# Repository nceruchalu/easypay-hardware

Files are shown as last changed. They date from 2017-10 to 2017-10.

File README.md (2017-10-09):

# EasyPay

Demo Video Click to watch EasyPay demo (https://www.youtube.com/watch?v=BhdTa_jyTG4)

## About EasyPay
| | |
| --- | --- |
| Author  | Nnoduka Eruchalu |
| Date | 05/16/2013 |
| Website | http://nnoduka.com/made/easypay/ |

EasyPay was intended to be Nigeria's One-Stop Payments Solution. It aimed to
support payments for multiple services like cellphone topup, water, power, TV
bills with hopes of expanding into retail and transportation someday.

## Documentation
* [**How it Works**](Documentation/HowItWorks.md): Notes on intended application
* [**Demo**](Documentation/Demo.md): Showcase of product features

## Repository Contents
| Module | Description |
| --- | --- |
| **/Documentation** | Design notes, datasheets, reference notes |
| **/Firmware** | Embedded C project |
| **/Hardware** | Altium design files |
| **/Production** | Production files used for printing PCBs |

## Version History
* 1.0.0: Demo Product

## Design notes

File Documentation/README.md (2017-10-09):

# Documentation

This directory contains documentation on the product modules.

## Directories

Brief description of directories. Add a brief description when adding a new
directory. Keep list in alphabetical order.

### [/Datasheets](Datasheets)
Resource files used in designing the circuit hardware.

## Modules

Brief description of modules. Add a brief description when adding a new module.
Keep list in alphabetical order.

### [Data.md](Data.md)
3G + GPS module for use in communication with the web server.

### [Demo.md](Demo.md)
Description and video of user interface created to showcase product features.

### [Enclosure.md](Enclosure.md)
Product enclosure details

### [Headers.md]([Headers.md)
Header and receptacle descriptions.

### [HowItWorks.md](HowItWorks.md)
Short description on the intended usage of the product

### [Keypad.md](Keypad.md)
Matrix keypad scanning, anti-aliasing, and interrupt generation.

### [LCD.md](LCD.md)
4x20 Character LCD connection and power up/down.

### [MCU.md](MCU.md)
PIC18F MCU configuration and clock choice (and how it relates to UART).

### [MIFARE.md](MIFARE.md)
MIFARE summary notes and testing strategy.

### [PCB.md](PCB.md)
PCB design requirements.

### [Power.md](Power.md)
Generation of 3.3V (for the MCU and peripherals) and 3.8V (for the data module)
regulated voltages from the battery voltage.

### [StateMachine.xlsx](StateMachine.xlsx)
Firmware's state machine design.

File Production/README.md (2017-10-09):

# Production

This directory contains the production files used for printing PCBs.

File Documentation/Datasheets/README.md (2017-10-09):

# Documentation/Datasheets

This directory contains resource files used in designing the circuits and
product.

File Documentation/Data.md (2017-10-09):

# Data Module

## Overview
[SIM5218](http://simcom.ee/modules/wcdma-hspa/sim5218/), a 3G + GPS module.

### Bands
Quad-band GSM/GPRS/EDGE and UMTS that works on frequencies of:
GSM 850MHz, EGSM 900MHz, DCS 1800MHz, PCS 1900MHz and WCDMA 900MHz/2100MHz

These work for:
* US bands:
  - 2G: GSM 850, GSM 1900
  - 3G: UMTS 850, UMTS 1900, UMTS 1700, UMTS 2100

* Nigeria bands:
  - 2G: GSM 900, GSM 1800
  - 3G: UMTS 2100

### Antenna
The antenna connector (module side) is MURATA MM9329-2700

### Connector
70 pins board-to-board

### I/O
Inputs pulled down (unless explicitly instructed otherwise) to minimize noise.

### Sim Card
Keep USIM peripheral circuit close to USIM card socket.

### Power
Required input Voltage Source = 3.4V to 4.2V
Normal value is 3.8V (so we use that!)
        
Current drawn could get up to 2A, so power supply should be able to do that.
        
**Note** that supply power should NEVER drop below 3.4V even in a transmit burst
during which current consumption may rise up to 2A.

### Power On/Off
Will do this via the POWER_ON pin (PIC's DATAPOWER) because it seems you can't
turn on the SIM5218A with AT commands.
To do this I will use an NPN transistor switch (really an inverting buffer)

More on transistor switches here:
* http://www.technologystudent.com/elec1/transis1.htm
* http://hyperphysics.phy-astr.gsu.edu/hbase/electronic/transwitch.html
        
More on inverting buffers here:
* http://hyperphysics.phy-astr.gsu.edu/hbase/electronic/buffer.html#c4

**Note** that the POWER_ON pin has been pulled up in module, so the internal
pull up counts as the load on the Collector.

### Reset
Just like the Power_ON pin, it has been pulled up in module, so will use a
similar switch.

### UART
UART_RX line has VIHmax = VDD_EXT + 0.3 = 2.6V + 0.3 = 2.9V
This means we need to use a  buffer to convert the RX input from the PIC to an
appropriate voltage. This will be done with an SN74LVC1G126. The voltage level
of the buffer will be set by the module's VREG_AUX which is set at 2.85V.

The UART_TX line has VOHmax = VDD_EXT = 2.6V and VOHmin = VDD_EXT-0.2 = 2.4V
So this doesn't have to be buffered because it goes into the PIC and the PIC can
handle Voltages less than VCC (3.3V).
Also the PIC's VIHmin for Schmitt Trigger inputs is 0.8V, so 2.4V isnt a too low
VIN. The PIC's USART pins are Schmitt Trigger inputs.

### Camera
No need to pull low (to prevent floating inputs)
Will be configured as GPIO (AT+CCGSWT)
Inputs pulled low to prevent floating inputs -- waste of power

### GPIO4
Pull high to turn off flight mode (RF is working)

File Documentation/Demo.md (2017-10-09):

# Product Demo
## User Interface
#### Keypad:
```
+---------------------------+
| 1       2       3       A |
|                           |
| 4       5       6       B |
|                           |
| 7       8       9       C |
|                           |
| *       0       #       D |
+---------------------------+
```

#### Display:
###### Welcome Screen:
```
+--------------------+
|-Welcome to EasyPay-|
|                    |
| Tap Card to Start  |
|                    |
+--------------------+
```

###### On Card Tap --> Enter Pin Screen:
```
+--------------------+           +--------------------+ 
|-    Enter Pin     -|           |-    Enter Pin     -|
|        _           |  <0..9>   |        ****        |
|*Exit*           → C|   ==>     |*Undo*           → C|
|*Done*           → D|           |*Done*           → D| 
+--------------------+           +--------------------+
```

###### On Correct Pin --> Home Screen:
Press buttons indicated on right to navigate
```
+--------------------+ 
|EasyAccount      → A|
|Parking          → B|
|Mobile Recharge  → C|
|Utility Bills    → D|
+--------------------+
```

###### EasyAccount Screen:
```
+--------------------+ 
|-   EasyAccount    -|
|Balance: N50,000.00 |
|Recharge         → C|
|*Exit*           → D|
+--------------------+
```

###### Parking Screen:
```
+--------------------+           +--------------------+ 
|- Pay for Parking  -|           |- Pay for Parking  -|
|Enter Space: 010_   |    <D>    |Enter Time: 0:30_   |
|                    |    ==>    |                    |
|*Done*           → D|           |*Done*           → D|
+--------------------+           +--------------------+ 
```

###### Mobile Recharge:
```
+--------------------+           +--------------------+ 
|- Mobile Recharge  -|           |*Back*           → A|
|MTN              → B|    <D>    |Airtel           → B|
|GLO              → C|    ==>    |Etisalat         → C|
|*More*           → D|           |*Exit*           → D|
+--------------------+           +--------------------+ 
```

###### Utility Bills:
```
+--------------------+           +--------------------+   
|-  Utility Bills   -|           |- Utility: Power   -|
|Power            → B|    <B>    |Amount: N10,000.00_ | 
|Water            → C|    ==>    |                    | 
|*Exit*           → D|           |*Done*           → D|
+--------------------+           +--------------------+
```

## Video
Click on the video below to see  a demo of the prototype module in action:

Demo Video (https://www.youtube.com/watch?v=BhdTa_jyTG4)

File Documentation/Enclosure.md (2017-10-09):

# Enclosure
## Overview
[OKW Enclosures A9061119](https://www.okwenclosures.com/en/Hand-Held-Boxes/A9061119.htm)

## Dimensions
Margins defined as dimension from exterior of enclosure to interior (pcb space)

### Top/Bottom margin calculation
    155 + 25 - 168 = 12mm
    So top/bottom margin = 12/2 = 6mm

### Left/Right margin calculation
    100-91 = 9
    So top/bottom margin = 9/2 = 4.5mm

### Inner space
    height                                    = 13.7 + 16.2 - 3      = 26.9mm
    height [sans pillars and other obstacles] = 9.7 + 16.2 - 5 - 2.8 = 18.1mm

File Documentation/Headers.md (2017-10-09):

# Headers and Receptacles
## Headers
    P1 - short (6 pins)            ICSP connector
    P2 - short/long (6 pins)       UART (uses jumper wires)
    P3 - short (8 pins)            Keypad connector
    P4 - external, short (6 pins)  RFID module
    P5 - long (16 pins * 2)        On pcb and lcd modules (use jumpers wires)
                                   * Should have used short
    P6 - short (3 pins)            LCD power selector (use jumpers)
    P8 - short  (8 pins)           Test points for power [**optional**]
 
    P7 - JST (2 pins)              External PWR connector (solder stranded wire)
    S2 - JST (2 pins)              System power switch (solder stranded wire)
    BT1 - JST (2 pins)             Battery connector

## Receptacles
    P4 - short(6 pins)              RFID receptacle

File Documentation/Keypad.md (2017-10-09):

# Keypad

## Module
[27899PAR-ND](https://www.digikey.com/product-detail/en/parallax-inc/27899/27899PAR-ND/3523678)

## 4x4 Matrix Layout

                    |Col0       |Col1       |Col2       |Col3
                    |           |           |           |
                    |           |           |           |
             ___/ --x    ___/ --x    ___/ --x    ___/ --x
    Row0     | SW0  |    | SW1  |    | SW2  |    | SW3  |
    ---------x------|----x------|----x------|----x------|
                    |           |           |           |
                    |           |           |           |
             ___/ --x    ___/ --x    ___/ --x    ___/ --x
    Row1     | SW4  |    | SW5  |    | SW6  |    | SW7  |
    ---------x------|----x------|----x------|----x------|
                    |           |           |           |
                    |           |           |           |
             ___/ --x    ___/ --x    ___/ --x    ___/ --x
    Row2     | SW8  |    | SW9  |    | SW10 |    | SW11 |
    ---------x------|----x------|----x------|----x------|
                    |           |           |           |
                    |           |           |           |
             ___/ --x    ___/ --x    ___/ --x    ___/ --x
    Row3     | SW12 |    | SW13 |    | SW14 |    | SW15 |
    ---------x------|----x------|----x------|----x------|

Keyboards use a matrix with the rows and columns made up of wires. Each key acts
like a switch. When a key is pressed, its column and row wires make contact.

## Scanning to Detect Key Presses
I order to detect key presses, the MCU (Micro Controller Unit) will scan all
rows, activating each one by one. When a row is activated, the MCU detects
columns are activated.

The row values will be active low outputs from the MCU (Micro Controller Unit).
So they are inputs into the keypad.

The column values will be active low inputs into the MCU.
So they are outputs from the keypad.
Since these are active low they have to be puled up by default, to an inactive
state.

Assuming the data for the rows are sent out in nibbles having Row3 as MSB and
Row0 as LSB i.e. (Row3, Row2, Row1, Row0), when we scan we get:

    row 0, send out 1110
    row 1, send out 1101
    row 2, send out 1011
    row 3, send out 0111

If Switch8 happens to be pressed when row 2 is activated (1011), then the MCU
input from the columns nibble (Col3, Col2, Col1, Col0) will be 1110 because
Column 0 will now be active.

### Multiple Keys Pressed
#### In a situation where SW0,1,5 are pressed:
* When scanning Row0, 1110 is sent out and the input to the MCU is 1100 showing
  SW0 and SW1 are pressed.
* When scanning row 1, 1101 is sent out and the input to the MCU is still 1100
  implying SW4 and SW5 are pressed. But SW4 isn't pressed!

#### Here is Why (Intro to Ghosting)
* When Row1 is set to 0, SW5 being pressed pulls down Col1.
* However SW1 is connected to Col1, and SW1 connects Col1 to Row0. So Row0
  is activated to a 0, despite the MCU setting it to 1.
* Remember SW0 connects Row0 to Col0, so SW0 activates Col0 as it did when Row0
  was activated by the MCU.
* So the MCU reads in a keypad value with both Col1 and Col0 activated, hence
  1100. This is called **ghosting**!

#### Masking
We have defined ghosting. Masking is the reverse.
If SW0,1,4,5 were all pressed, and SW0 was released the MCU wouldn't know, as it
would again assume all 4 keys were still pressed. This is called **masking**!

#### Problem for MCU (And Solution)
Let's work with the ghosting case. The real issue was that Row0 was activated
by SW1 even when the MCU was attempting to deactivate it. This creates a
conflict and surely cannot be good for the MCU; it is indirectly setting an I/O
pin both active and inactive at the same time. You want to protect the MCU from
this, and you need diodes for this!

Position diodes on all the output pins of the MCU with the cathode (-ve) at the
MCU and the anode at the keypad.

This won't solve ghosting, but it protects the MCU from receving a 0 on Row0
when it is setting it to a 1. Remember how diodes work: the anode have to be at
a higher potential than the cathode by at least the forward voltage for any
current to flow.

                     |Vcc        |Vcc        |Vcc        |Vcc
                     |           |           |           |
                   |---|       |---|       |---|       |---|  
                   |   |       |   |       |   |       |   |
                   |10K|       |10K|       |10K|       |10K|
                   |   |       |   |       |   |       |   |
                   |---|       |---|       |---|       |---|
              Col0   |    Col1   |    Col2   |    Col3   |                
              -------|    -------|    -------|    -------|
                     |           |           |           |
              ___/ --x    ___/ --x    ___/ --x    ___/ --x
    Row0      | SW0  |    | SW1  |    | SW2  |    | SW3  |
    ----|<|---x------|----x------|----x------|----x------|
                     |           |           |           |
                     |           |           |           |
              ___/ --x    ___/ --x    ___/ --x    ___/ --x
    Row1      | SW4  |    | SW5  |    | SW6  |    | SW7  |
    ----|<|---x------|----x------|----x------|----x------|
                     |           |           |           |
                     |           |           |           |
              ___/ --x    ___/ --x    ___/ --x    ___/ --x
    Row2      | SW8  |    | SW9  |    | SW10 |    | SW11 |
    ----|<|---x------|----x------|----x------|----x------|
                     |           |           |           |
                     |           |           |           |
              ___/ --x    ___/ --x    ___/ --x    ___/ --x
    Row3      | SW12 |    | SW13 |    | SW14 |    | SW15 |
    ----|<|---x------|----x------|----x------|----x------|

Make your life easy and use 1N4148 switching diodes.

#### How to fix Aliasing (Ghosting and Masking)
The 4 diodes placed on the rows will protect the MCU but won't solve aliasing.
To solve ghosting let's look back at our example. We need that Row0 will not be
activated by SW1 while scanning Row1. To do this we need a diode between SW1 and
Row0, with the cathode at Row0.

This has to be built into they keypad. You cannot add this in external circuitry

##### Ref
http://www.dribin.org/dave/keyboard/one_html/

## Keypad Interrupts
To conserve power, the MCU should be able to go to sleep.
Before it does that, all rows should be activated by setting them to 0. This
means that when any key is pressed, the corresponding MCU input will be 0.
Remember that the MCU inputs are the keypad columns which are pulled-up to Vcc,
so a Diode-Resistor AND gate should be placed on the columns. The idea is once
one Column goes from 1 to 0, then the output of the gate will go from 1 to 0,
and create a pulse that should be connected to an MCU SYSTEM_WAKEUP pin.
            
                Vcc
                 |
               +---+
               |   |
               |10K|
               +---+
                 |
    Col0 --|<|---+------- SYSTEM WAKEUP (Col0 & Col1 & Col2 & Col 3)
                 |
    Col1 --|<|---+
                 |
    Col2 --|<|---+
                 |
    Col3 --|<|---+

##### Ref
https://en.wikipedia.org/wiki/Diode_logic#AND_logic_gate

## Connector
    Black           White

    R1 R2 R3 R4     C1 C2 C3 C4

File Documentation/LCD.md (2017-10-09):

# LCD
## Module
[NHD-0420AZ-FSW-GBW-33V3](http://www.newhavendisplay.com/specs/NHD-0420AZ-FSW-GBW-33V3.pdf)

## Backlight
Typical specs: 3.0V and 15mA

However system voltage is 3.3V, so the solution here is to burn off the extra
0.3V across a series resistor. If this resistor has 15mA passing through it,
to burn off 0.3V we need 0.3/0.015 Ohms = 20 Ohms.
Backlight series resistor will be 20 Ohms.

## Power
Supply Power Typical specs: 3.3V, 2mA
Supply Power Max specs:     5.5V, 3mA

This means the system uses a total of (15 + 3)mA between VDD and backlight.
Lets put this at 20mA tops.

The LCD power (VCCLCD) could come from:
* The system, VCC
* The MCU PIC, VCCLCD_PIC.
  The PIC MCU's PortA<7:6>, PortB, PortC can output up to 25mA.

Using VCCLCD_PIC has the advantage of being able to turn off the LCD module
via the PIC.
After some testing, will see if this is a viable solution.

## Contrast
Using a 10KOhms potentiometer to decide on the contrast.
Eventually this should be replaced by either a pull-up or pull-down, for 
maximum contrast.

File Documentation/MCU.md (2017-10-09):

# Micro Controller Unit (MCU)
## Module
[PIC18F67K22](http://www.microchip.com/wwwproducts/en/PIC18F67K22)

## Low Power Tips 'n Tricks
* Using I/O pins to power external components:
  - **LCD**: VCCLCD_PIC is a PIC I/O line powering LCD since LCD utilized less
    than 20mA
  - **RFID Module**: Work current could get up to 45mA, so cant power with a
    PIC I/O, so will send the Power Down commands and use the wakeup signal to
    restart it.
  - **Data Module**: Again draws high current (and uses 3.8V) so cant power via
    I/O, so will send Power Down and Power Up signals to it.

* Will be in sleep mode when not active, and will be woken up by SYSTEM_WAKEUP
  interrupt from the keypad

* Configuring Port Pins:
  Unused Port Pins: will be configured as output pins driving to either state
  (high or low).

* Using high-value pull up resistors (10K Ohms)

## External Clock (SG636PCE 18.4320MC0)
Using a high precision external clock of 18.432MHz to have 0% Baud Rate Error.
The desired Baud rate is 115.2KHz, to satisfy the default value of the data
module.

## On-Chip Regulator
This is enabled

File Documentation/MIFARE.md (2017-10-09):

# MIFARE 
## MIFARE Classic Intro
http://www.ladyada.net/products/rfidnfc/mifare.html

## MIFARE DESFire
Model:                     MF3 1C D40
Free Space:                4K
Max. Apps:                 28
Max. Keys per app.:        14 (counting master key 0) [for apps AID != 0x00 ]
Max. Files per app.:       16
Crypto:                    DES, 3DES
Support for ISO 7816 Cmds: Very Limited

'Compatible Crypto Mode' must be used

MiFare DESFire are iso14443A compliant contactless smartcards, and support all
layers including iso4443-4. Think of these cards as memory cards
with access control. 

The new DESFire EV1 cards are supposed to address the flaws found in v0.6

### Introduction
* http://www.waazaa.org/download/fcd-14443-4.pdf
* http://ridrix.wordpress.com/2009/09/19/mifare-desfire-communication-example/

### MAD and MIFARE DESFIire
Every application has a 3 byte Application Identifier (AID) 

Available File Types:
Files within an application can be any of the following types
* Standard data files
* Backup data files
* Value files with backup
* Linear record files with backup
* Cyclic record files with backup

The AID 0xFFFFFF is reserved. It is used to store general issuer information.
* File 0x0 has to be a value file with free access for GetValue, holding the
  value 0x000003 indicating the MAD version 3.
* File 0x1 shall be configured as StandardDataFile with free read acess. This
  file holds the contact details of the Card Holder (user of the card) in CSV
  plain text. [Section 3.5 of MAD]
* File 0x2 shall be configured as StandardDataFile with free read access. This
  file holds the contact details of the Card publisher (owner of the PICC Master
  Key) in CSV plain text. [Section 3.8 of MAD]
 File 0x3 to 0xF are RFU (Reserved for Future Use) and shall not be used within
  DESFire AID 0xFFFFFF. PCDs shall ignore these files 0x3 to 0xF

### DESFire Command Protocols
* ISO 14443A-3
  - Request Type A (REQA)
  - Wake-Up (WUPA)
  - Anticollision & Select Cascade Level 1
  - Anticollision & Select Cascade Level 2

* ISO 14443-4:
  - Request for Answer To Select (RATS)
  - Protocol and Parameter Selection (PPS)
  - Frame Waiting Extension (WTX)

* T=CL ("CL" means "contact less"):
  - PICC Command Set

### DESFire PICC Commands
Depending on the version of the card, a DESFire card might support commands in
native, native-wrapped or iso78166-4 command set styles.
* Software version v0.4 does not support APDU (only native commands)
* v0.5 adds support for wrapping native commands inside ISO7816 style APDUs
* v0.6 adds ISO/IEC 7816 command set compatibility

Use native commands for full compatibility with all DESFire cards, and for
access to all commands.

## Native Command Mode
Most of these commands are one byte long, and the card responds with
"statusbyte + [optional data]". See Datasheet for more.

### Status byte examples
    00 : Command successful
    af : More data (send command 'af' to fetch remaining data)
    9d : Permission denied

### Communication flow
    --> To card
    <-- From card

## Example (using a blank DESFire v0.6 card):
### Get Version
    --> 60
    <-- af 04 01 01 00 02 18 05
    --> af
    <-- af 04 01 01 00 06 18 05
    --> af
    <-- 00 XX XX XX XX XX XX XX ZZ ZZ ZZ ZZ ZZ 05 06

The first response denotes the hardware related data: version is 0.2 (00 02),
and storage size is 0x18 (4096 bytes)
The second response denotes the software related data: version is 0.6 (00 06),
and storage size is 0x18 (4096 bytes)
The X's are the 7-byte UID
The Z's are the 5-byte batch number
05 = Calender week of prodution
06 = Production year

### Get Application Ids
    --> 6a
    <-- 00
    
No applications available (blank card)

### Select PICC Application
    --> 5a 00 00 00
    <-- 00
    
OK

### Get File IDs (for PICC Application)
    --> 6f
    <-- 9d
    
Permission denied

### Get Key Settings (For PICC Application)
    --> 45
    <-- 00 0f 01
    
0f = All bits in lower nibble are set, meaning configuration can be changed,
     CreateApplication/GetApplicationIDs/GetKeySettings can be performed without
     master key, and master key is changeable
01 = Only 1 key can exists for this application (the PICC application)

### Get Key version for key 00 (for PICC Application)
    --> 64 00
    <-- 00 00
    
The PICC master key version is 0x00

### Authentication with key 00 (for PICC Application)
    --> 0a 00
    <-- af a2 be cd 03 d8 46 cb 33
    --> af b0 cc bc ed 8f c8 38 c9 08 dc e2 4d 86 ca ec 3c
    <-- 00 76 73 d9 49 71 3f f2 d1

The example only showed authentication with the PICC application. In a real
world transaction you would typically select a specific AID (!= 00 00 00),
authenticate, and then read/write to files within that application.

After a successful authentication, further communication with the card is done
in plain/plain+MAC/encrypted+MAC, depending on the access bits for the
particular file.

## Authentication
Authentication is done using DES or Triple-DES depending on keysize. If key is
8 bytes: Single DES. If key is 16 bytes, and the first 8 bytes of the key are
different from the last 8 bytes: Triple-DES. The card terminal (PCD) always uses
DECRYPT_MODE (both when receiving and sending encrypted data), and the card
always uses ENCRYPT_MODE. However, the DESFire crypto is a bit different from
the normal DES/CBC scheme: The PCD uses DES "send mode" when sending data (xor
before DES), and the card uses DES "receive mode" when receiving data (xor after
DES). But when the PCD receives data, it uses normal DES/CBC mode (xor after
DES), and the card uses normal DES send mode when sending data (xor before DES).

## DESFire encryption
| | Send encrypted data | Receive encrypted data |
|---|---|---|
| PCD (DECRYPT)  | DES/CBC "send mode" | Normal DES/CBC "receive mode"  |
| Card (ENCRYPT) | Normal DES/CBC "send mode" | DES/CBC "receive mode" |

## TEST FUNCTION (USING AN SL032)
Test_SL032:
* initialize card type var. to an unknown value;
* send cmd(SelectCard[0x01])
* set timer to countdown 30ms
* wait in a loop until at least one of following happens:
  - UARTstatus is rxerr [determined by checksum analysis on rx'd data]
  - UARTstatus is rxsucc
  - timer times out
* exit the function if one of the following happens:
  - UARTstatus not rxsucc
  - Rx'd Command not SelectCard[0x01]
  - Rx'd Status is not 'Operation Success'[0x00]
* read the returned 'Data' byte and assign card type appropriately
  it is a DESFire if value is 6  

### The next steps are for a DESFire card 
* send cmd(RATSDesFire[0x20])
* set timer to countdown 300ms
* wait in a loop until one of the following happens:
  - UARTstatus is rxerr
  - UARTstatus is rxsucc
  - timer times out
* exit the function if one of the following happens:
  - UARTstatus is not rxsucc
  - Rx'd Command is not RATSDesFire[0x20]
  - Rx'd Status is not 'Operation Success'[0x00]
* send cmd(DesFireGetVersion);
* set timer to countdown 300ms
* wait in a loop until one of the following happens:
  - UARTstatus is rxerr
  - UARTstatus is rxsucc
  - timer times out
* exit the function if one of the following happens:
  - UARTstatus is not rxsucc
  - Rx'd Command is not 'T=CL exchange'[0x21]
  - Rx'd Status is not 'Operation Success'[0x00]
* note this, smart card status is actually the 5th received byte (index at 4)
  i.e. it is the first data byte in "Reader to Host" communication with SL032
* exit function if smart card status doesnt say 'Additional Frame'[0xAF]
* send cmd(GetAdditionalData)
* set timer to countdown 300ms
* wait in a loop until one of the following happens:
  - UARTstatus is rxerr
  - UARTstatus is rxsucc
  - timer times out
* exit the function if one of the following happens:
  - UARTstatus is not rxsucc
  - Rx'd Command is not 'T=CL exchange'[0x21]
  - Rx'd Status is not 'Operation Success'[0x00]
* exit function if smart card status doesnt say 'Additional Frame'[0xAF]
* send cmd(GetAdditionalData)
* set timer to countdown 300ms
* wait in a loop until one of the following happens:
  - UARTstatus is rxerr
  - UARTstatus is rxsucc
  - timer times out
* exit the function if one of the following happens:
  - UARTstatus is not rxsucc
  - Rx'd Command is not 'T=CL exchange'[0x21]
  - Rx'd Status is not 'Operation Success'[0x00]
* exit function if smart card status doesnt say 'Operation OK'[0x00]
* if you get this far in the function, turn on the buzzer... 
* turn on light for 30ms
* done!

## TODO
1. why do we have to getadditional data twice, after cmd(DesFireGetVersion)?
2. why do we set timer to 300ms?

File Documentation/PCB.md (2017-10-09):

# PCB
## Dimensions
Save 1mm on both sides to create margin for error/minimize shock on pcb

    Width :89mm [max is 91mm]
    Length:166mm [max is 168mm]

### Corner Cuts (Avoid Pillars)
Note 1mm taken off of values (this is explained in dimensions)

           +-----------------------------+
           |9.5mm                 9.5mm| 12 - 6 + 3.25 = 9.25 [buffer -> 10.5]
           |                             | 
    +-----+                             +-----+
    |  9mm                                9mm |
    |                                         |
    |                                         |
    
    /\/\/\/\/\/\/\/\/\/\/\/\/\/\/\/\/\/\/\/\/\/
    
    |                                         |
    |                                         |
    |  9mm                                9mm |
    +-----+                             +-----+
          |                             |  
          |23.5mm                 23.5mm| (91-80)/2 + 3.25 =8.75 [buffer ->10.0]
          |                             | 25 - 6 + 3.25 = 22.25 [buffer -> 24.5]
          +-----------------------------+

### Inner Cut (For Battery)
    L: 69mm [max]
    W: 55mm [max]
    H: 28mm [max]

                      55mm
                    ------->  
            +--------------+ /|\
            |              |  |69mm
            |              |  |
            |              |  
            |              |
            |              |
            |              |
            |              |
            |              |
     17mm   |              |
    ------->+--------------+
           /|\
    Bottom  |0mm
    Left    |

Bottom Left offset is calculated by:
    x = width(89 - 55)/2 = 17mm
    y = maximize pcb space =  0mm

## Board Layers
* Signal Layers: 2
* Power Planes: None = 0

## Via Style
* Thruhole vias only

## Component and Routing Tech
* Surface Mount components
* Components on both sides of the board: Yes

## Default Track and Via Sizes
Using 10/10 (track/clearance) rules for ease of hand soldering.
* Minimum Track Size: 10mil
* Minimum Via Width: 50mil
* Minimum Via HoleSize: 28mil
* Minimum Clearance:10mil

## Design -> Rules
* Mask -> SolderMask Expansion: 5mil
* Routing -> Width -> Power_Width:        
  - **Belongs to Net**: VBATT, VCC, VCC38, VCCLCD, VCCLCD_PIC, VCHARGE,
    VDDCORE, VREG_AUX, V_USIM, GND
    **Note**: Use an OR operand between the nets.
  - **Min/Preferred/Max Widths**: 25mil/25mil/100mil [Top & Bottom Layer]
* Minimum SolderMaskSliver: Default = 10mil    
* SMD Neck-Down: 100%                               

## Board Outline
Draw it with mechanical layer 2

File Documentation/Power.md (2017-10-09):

# Power

## Battery Terminology
Battery is Lithium Iron Phosphate (LiFePO4)

* **C-rate** is a measure of the rate at which a battery is discharged relative
  to  its maximum capacity. A 1C rate means that the discharge current will
  discharge the entire battery in 1 hour. For a batter with a capacity of
  100Amp-hrs this equates to a discharge current of 100 Amps. A 5C rate for this
  battery would be 500 Amps, and a 0.5C rate would be 50Amps.

* **Nominal Voltage**: The reported or reference voltage of the battery

* **Cut-off Voltage**: The minimum allowable voltage. This voltage generally
  defines the empty state of the battery

* **Capacity or Norminal Capacity (Ah for a specific C-rate)**: The coulometric
  capacity, the total Amp-hours available when the battery is discharge at a
  certain discharge current (specified as a C-rate) from 100 percent to cut-off
  Voltage.
  Capacity is calculated by multiplying the discharge current (in Amps) by the
  discharge time (in hours) and decreases with increasing C-rate.

* **Max Continuous Discharge Current**: The maximum current at which the battery
  can be discharged continuously.

* **Charge Voltage**: The voltage that the battery is charged to when charged to
  full capacity. Charging schemes generally consist of a Constant Current (CC)
  charging until the battery voltage reaches the charge voltage, then
  Constant Voltage (CV) charging, allowing the charge current to taper until it
  is very small.

* **Float Voltage**: the voltage at which the battery is maintained after being
  charged to 100% SOC (State of Charge) to maintain  that capacity by
  compensating for self-discharge of the battery.

* **(Recommended) Charge Current**: The ideal current at which the battery is
  initially charged (to roughly 70% SOC) under constant charging scheme before
  transitioning to constant voltage scheme.

## Battery Specs
* Supplier: BCC Electronics
* Capacity: 3Ah
* Nominal Voltage: 6.4V
* Max End-of-Charge Voltage: 7.2V
* Low Voltage Cut-off Voltage: 4V
* Standard Charge Current (during CC charging): 0.2C to 2C [0.6A to 6A]
* CV charging end current : < 0.1C
* Max Continuous Discharge current: 0.5C [1.5A]
* Max Discharge: 15C [45A]
* Cycle Life >= 2000 times
* Charge time with 0.2C charge current in CC mode: 5 hours
* Built in protection (over charge and over discharge) circuitry.
* Cell dimensions: 26 diameter x 65mm (each 26650 cell is just 3.2 V)
* Battery Pack dimensions: 28 x 55 x 69mm (2 cells side by side but in series)

## Battery Charger: (LT3652)
System still works in a no-battery condition, so for this put in a 100uF low ESR
non-ceramic (tantalum) capacitor from BAT pin to GND, in parallel with the 10uF
ceramic bypass cap. This 100uF cap also is needed when the battery is connected
to the charger with long wires.

* **LT3652_VIN** = VCHARGE = System input voltage
  - Solar Panel in production
  - Wall transformer in production
* **VCHARGE** has to be 3.3V greater than the programmed output battery float
  voltage for startup. But for operation, VCHARGE has to be 0.75V greater than
  VBATT
  - So on startup, VCHARGE >= 10.5V
  - For operation: VCHARGE >= 7.95

* **VIN_REG**: Used to program a minimum *operational* supply voltage, by using
  a resistive divider to set this pin at 2.7V
  
      Rin1/Rin2 = (VIN_Min/2.7) - 1
      Rin1/Rin2 = (8/2.7) - 1 = 1.96 ~ 2
      So using Rin1 and Rin2 as 200K and 100K

* **SHDN\\**: Charger is always on, so tied to VIN

* **CHRG\\**: sinks current (up to 10mA) when enabled so connect green LED here
  with cathode towards the pin, and anode at VIN

* **FAULT\\**: also sinks current so use red LED

* **TIMER**: disable by connecting to GND

* **VFB**: final voltage of this pin should be 3.3V. Using this, setup the final
  output voltage (float voltage) via a resistive divider.
  
      R1 = (VBATT * 2.5*10^5)/3.3 
      R2 = (R1 * 2.5*10^5)/(R1 - (2.5*10^5))  
      Use 7.1V for VBATT for battery safety to get R1=538K and R2 = 467K
      in current setup (470+536)/470 * 3.3V = 7.1V as final float voltage

* **NTC**: enable battery temp. monitor pin by connecting a 10KOhm, B=3380 NTC
  thermistor from this pin to GND.

* **BAT**: Connect to switch as a means of turning off the system

* **SENSE** Use to set the max. charge current (up to 2A)

        Rsense = 0.1/I_Chg(Max)
        Setting max charge current to 1A yields Rsense = 0.1 Ohms

* Inductor Selection
    L = (10*Rsense/Delta_I)*VBATT*[1- (VBATT/VIN_MAX)]
    Rsense = 0.1
    0.25 < Delta_I < 0.35
    VBATT = 7.1
    VIN_MAX = 18V
    ==> 12.3uH < L < 17.2 uH
    I picked middle ground of 15uH

* **SW**: The recitfier diode from this pin to GND is a Schotky diode with:
  - as low forward voltage as possible
  - rated to withstand reverse voltages greater than the max VIN
  - I_Diode(Max) = minimum average diode current rating
  
        I_Diode(Max) > I_Chg_Max*(VIN_Max - 0.7*VBATT)/VIN_Max
                     > 1*(18-0.7*7.1)/18
                     > 0.723A
                     for safety: > 1A
  - Picked a CDBA340L-G with reverse voltage rating of 40V, I_Diode(Max)=3A,
    Forward voltage = 0.4V at 3A

## VCC Generator (3.3V) [ADP3050ARZ-3.3]
Using "ADP3050 parts" for the design
* Vin (min) = 4.372V
* Vin (max) = 7.2V
* Vout = 3.3V
* Iout = 1A
* Design For = "Most Efficient"

Input voltage source is VBATT

However we are using an ADP3050-3.3 which is a fixed voltage buck converter,
so there will be some modifications based on the datasheet's Typical Application
Circuit (Figure 24)

* Inductor:

      L = [(VIN_Max - Vout)/Iripple] * (1/f_sw) * (Vout/VIN_Max)
      L = ((7.2 - 3.3)/0.3) * (1/200K) * (3.3/7.2)
      L = 30uH
  
      I_sw = Iout(max) + 0.5Iripple = 1 + 0.15 = 1.15A

  - So need an inductor with a saturation (or dc) current rating above
    1.2 * I_sw (1.38)

* Output Capacitor: 100uF low ESR

* Catch Diode:

      I_Diode_Avg = Iout * (Vin-Vout)/Vin
                  = 1 * (7.2-3.3)/7.2
                  = 0.54A

  - Current rating must be at least 0.54A
  - Low forward voltage
  - MBRS330T3G works

* Input Capacitor:

      Icin_Rms >= Iout * SQRT[(Vout/Vin) - (Vout/Vin)^2]
               >= 1 * SQRT[(3.3/7.2) - (3.3/7.2)^2]
               >= 0.5A
  - So RMS ripple current rating must be at least 0.5A
  - GRM31CR71E475K works (4.7uF)

## VCC38 Generator (3.8V) [TPS54331D]
Use "SwitcherPro"
* VinMin = 4.67V
* VinMax = 7.3V
* Vout   = 3.8V
* Iout   = 3A

Input Voltage Source is VBATT

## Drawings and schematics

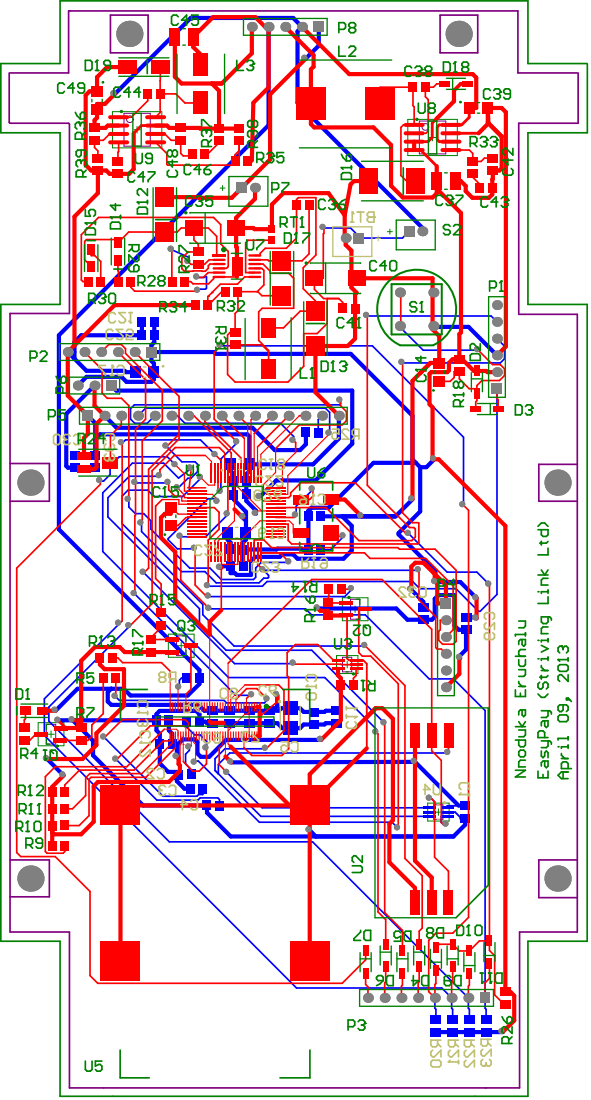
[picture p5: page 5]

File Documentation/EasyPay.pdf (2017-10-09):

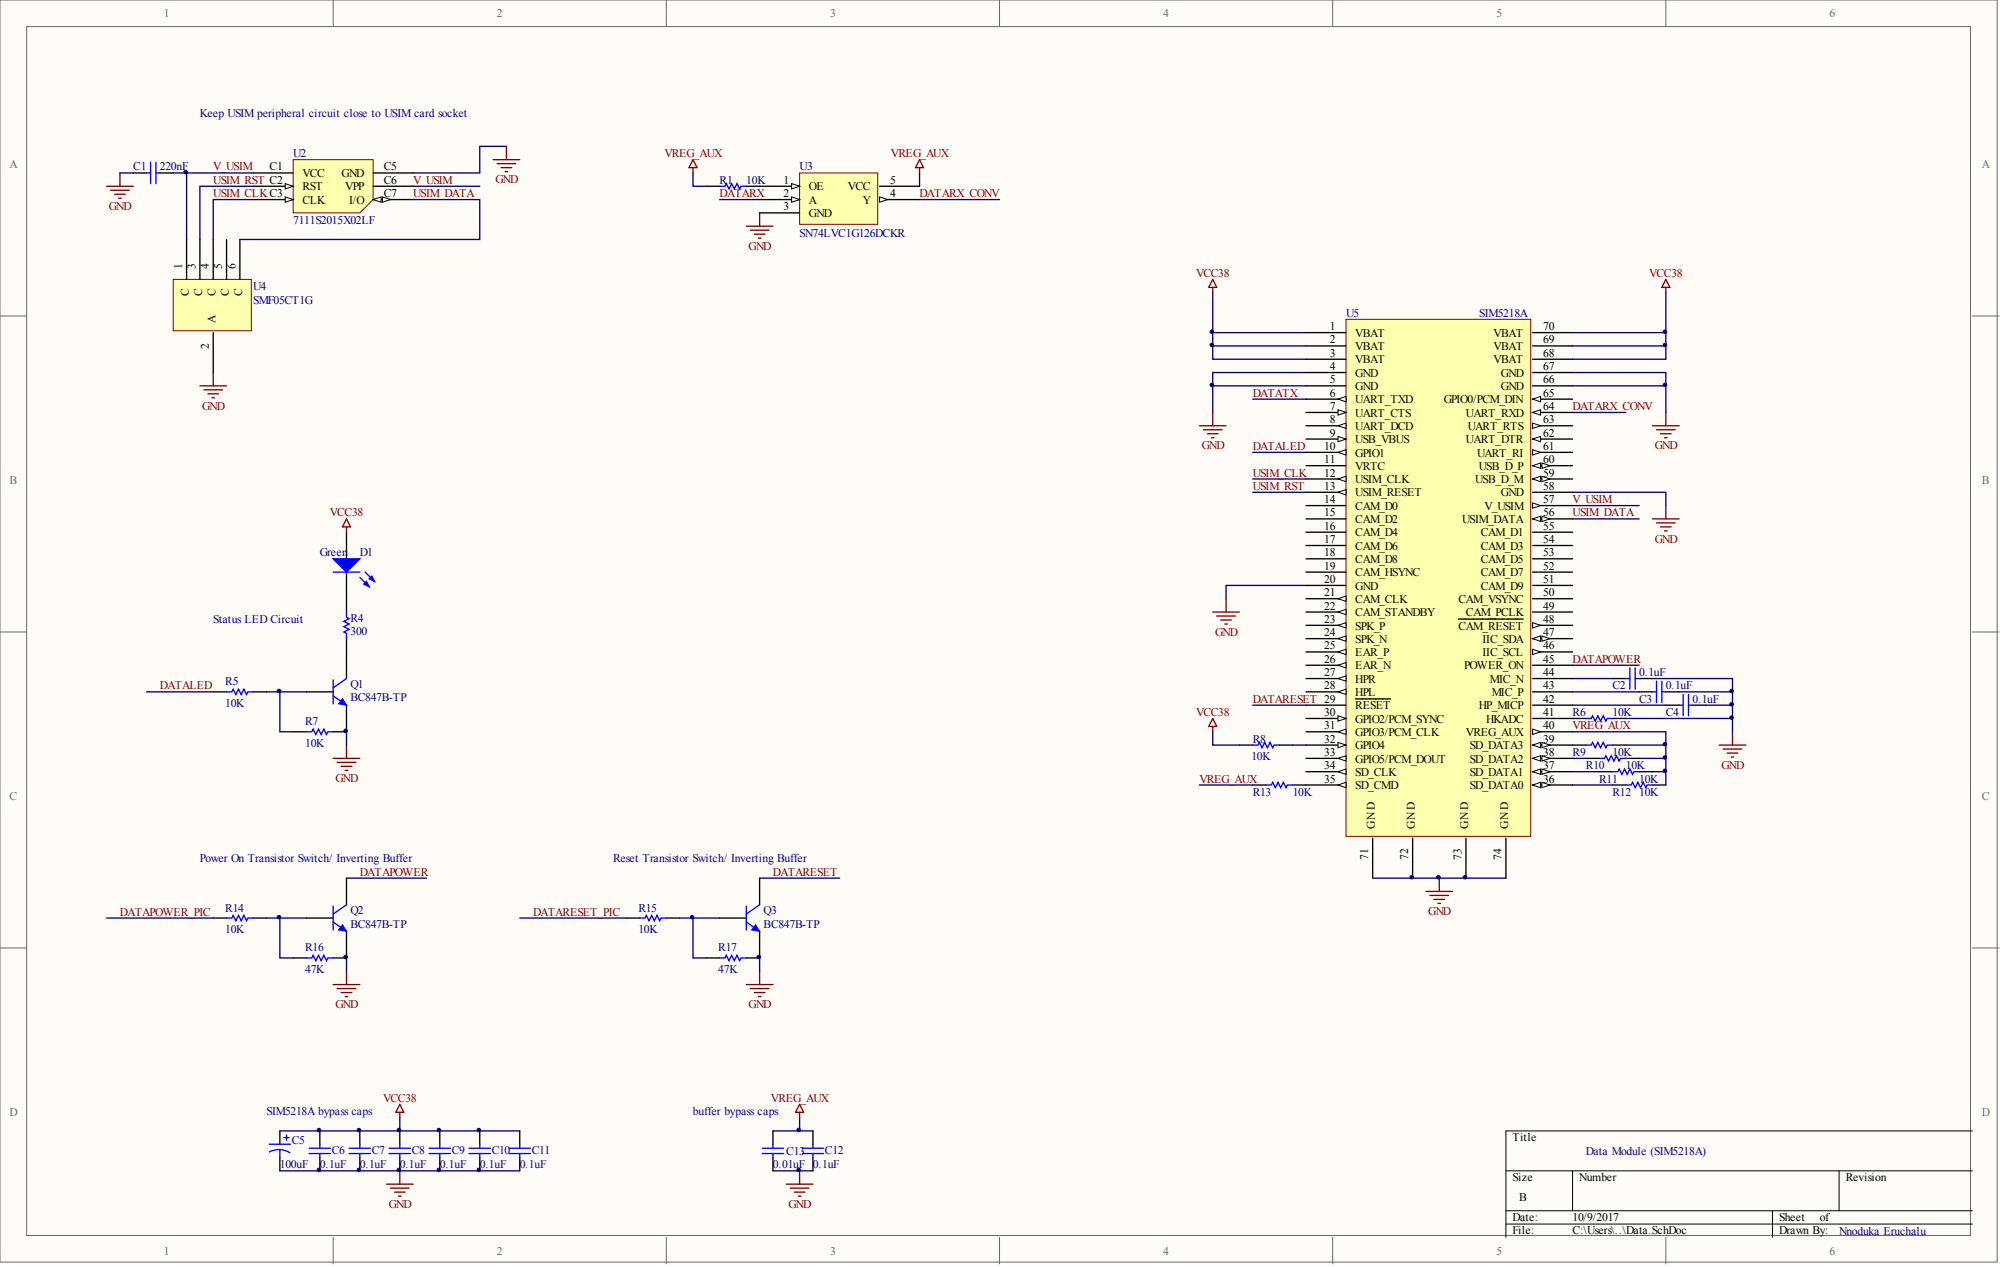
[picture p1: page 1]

Keep USIM peripheral circuit close to USIM card socket

GND 5

DATATX | UART_TXD 6 UART_CTS 7 | DATARX_CONV

V_USIM

CAM_D2 15 | USIM_DATA

HPL 28 | C2 | 0.1uF
RESET 29 GPIO2/PCM_SYNC 30 | C3 | 0.1uF

Power On Transistor Switch/ Inverting Buffer

Reset Transistor Switch/ Inverting Buffer

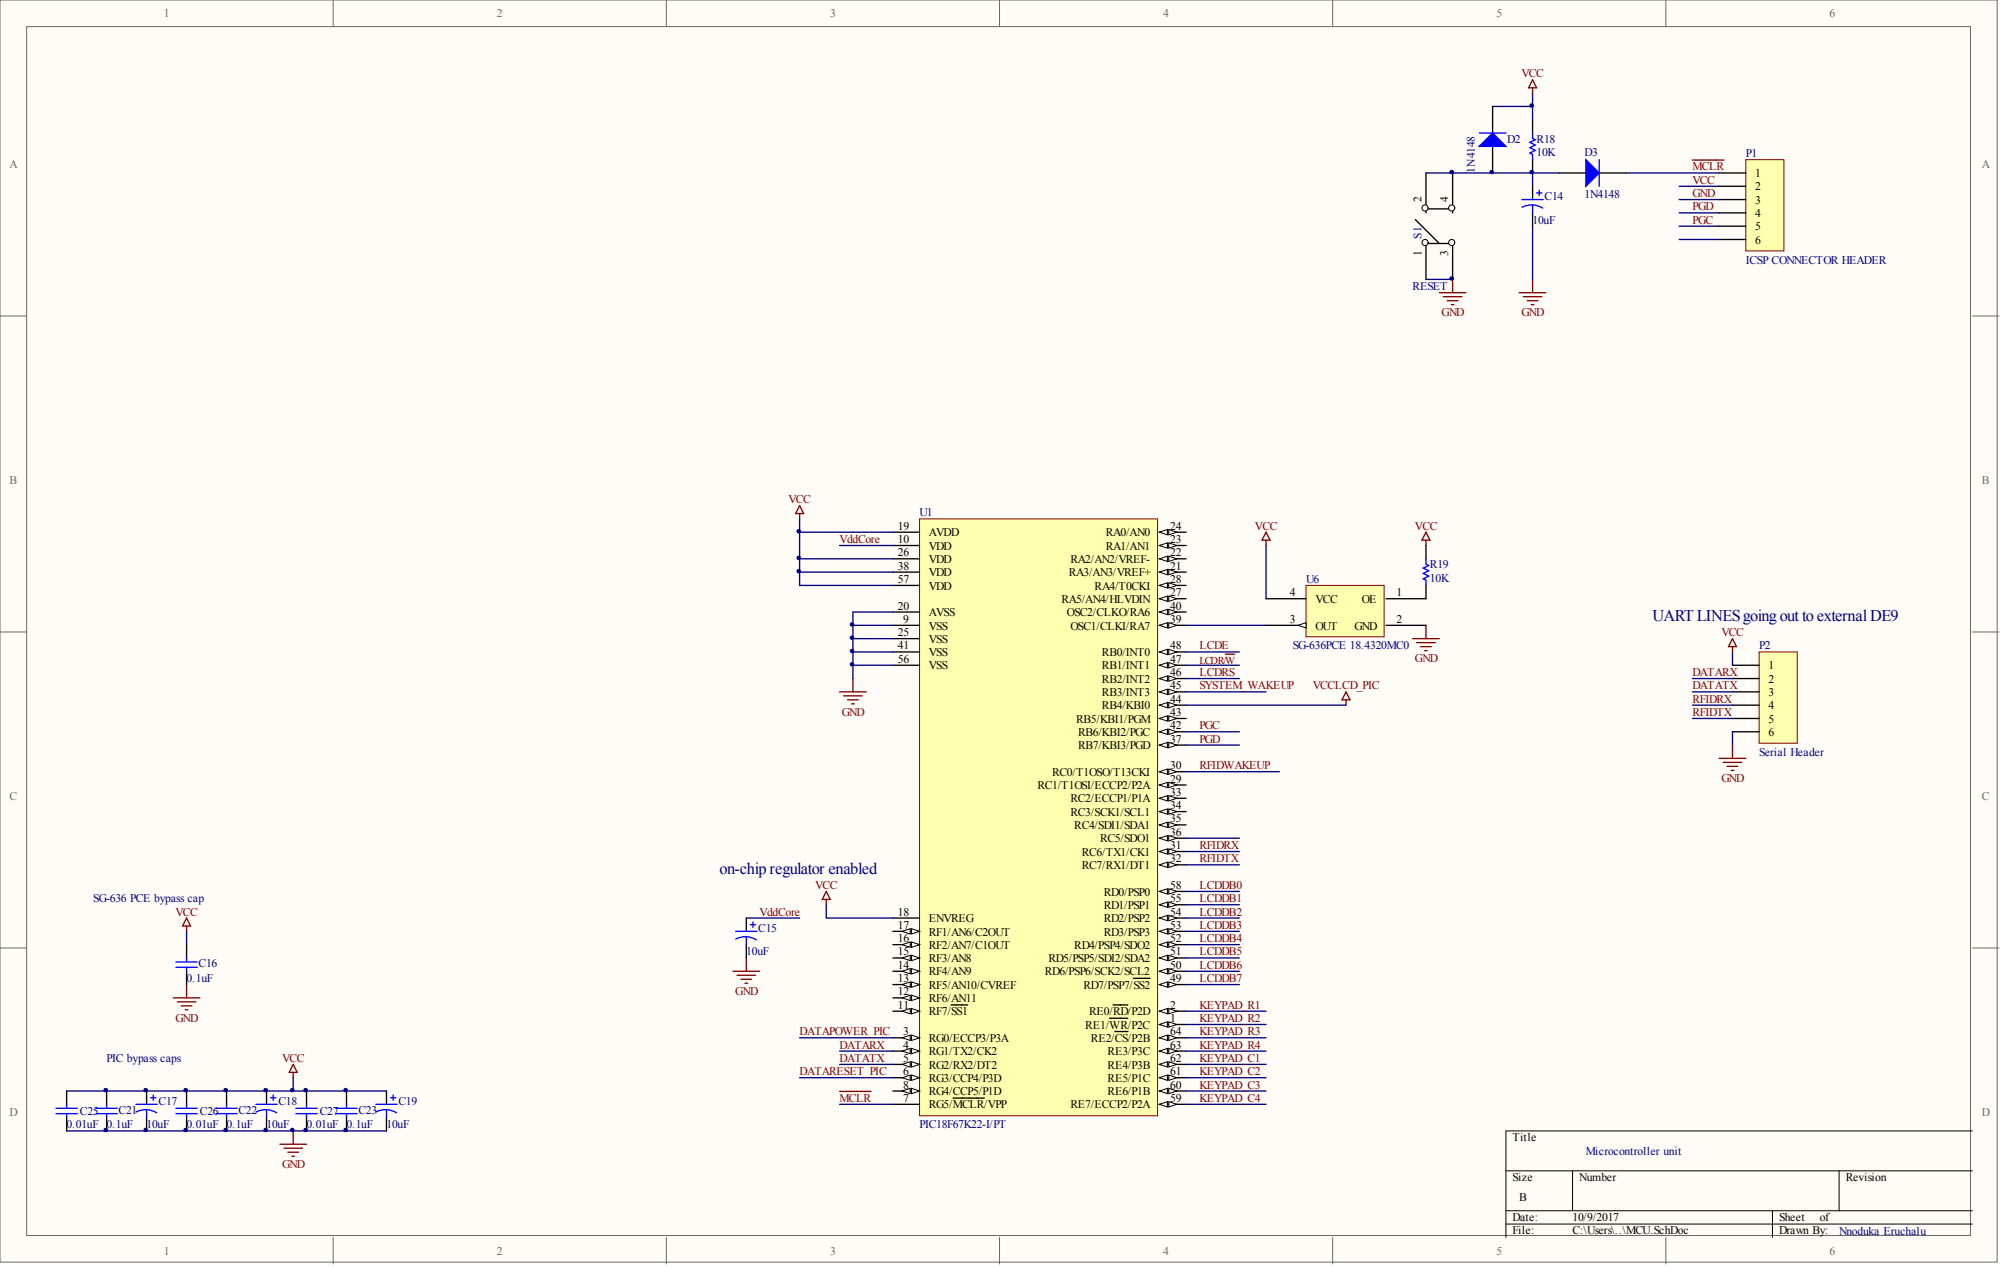
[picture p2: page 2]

Vdd C o r e | 1 0 2 6

3 8
5 7

2 5
4 1

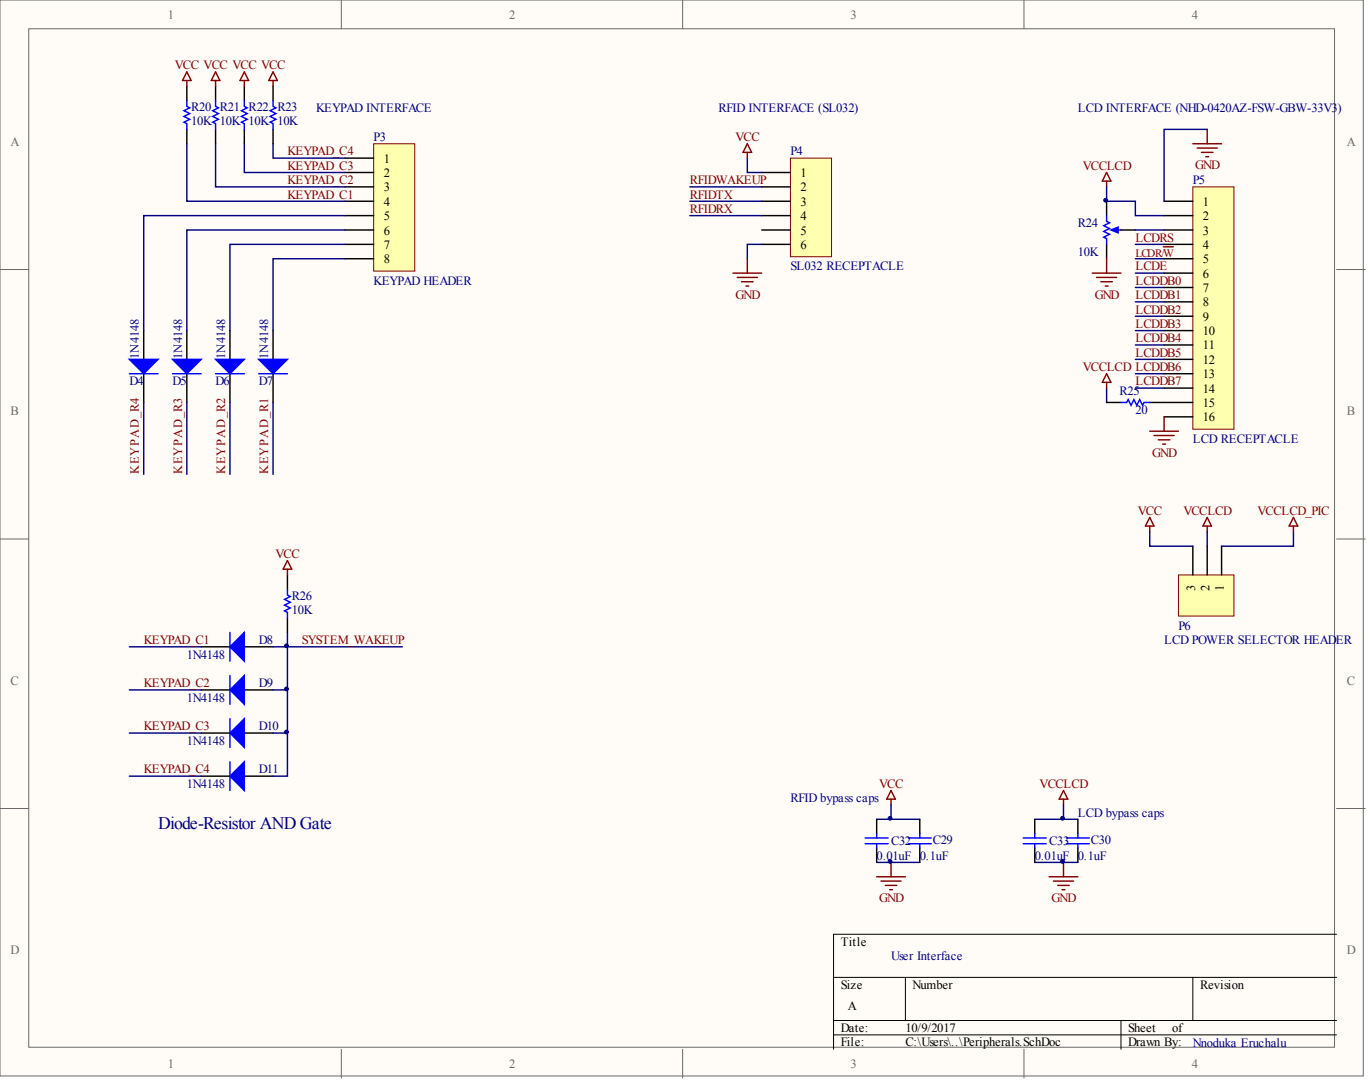
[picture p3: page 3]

LCD POWER SELECTOR HEADER

Diode-Resistor AND Gate

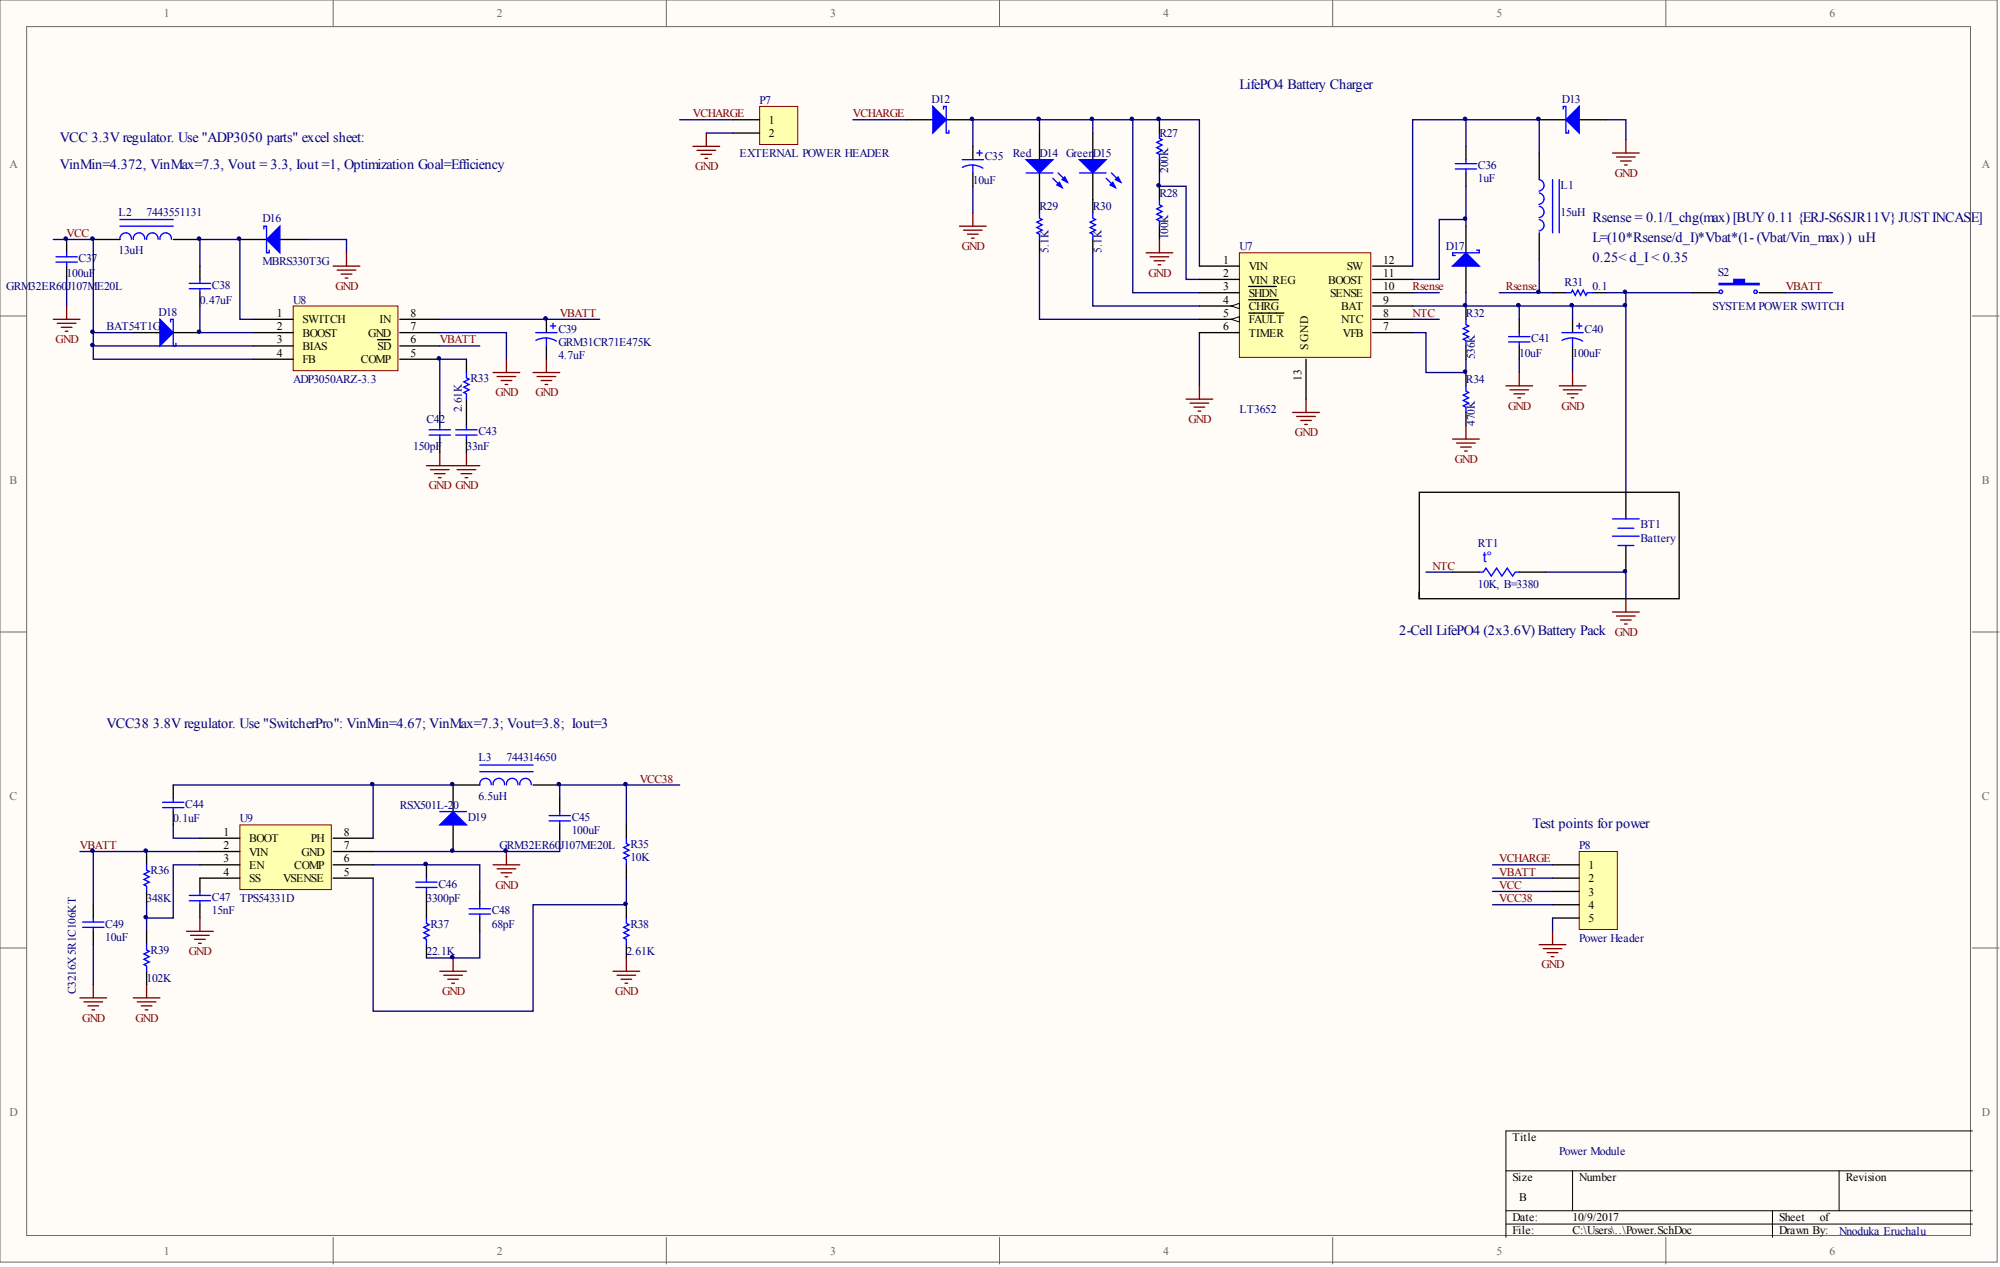
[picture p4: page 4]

VCC 3.3V regulator. Use "ADP3050 parts" excel sheet:

VinMin=4.372, VinMax=7.3, Vout = 3.3, Iout =1, Optimization Goal=Efficiency

Rsense = 0.1/I_chg(max) [BUY 0.11 {ERJ-S6SJR11V} JUST INCASE]
L=(10*Rsense/d_I)*Vbat*(1- (Vbat/Vin_max) ) uH

BOOST 2
BIAS 3 | VBATT

2-Cell LifePO4 (2x3.6V) Battery Pack GND

VCC38 3.8V regulator. Use "SwitcherPro": VinMin=4.67; VinMax=7.3; Vout=3.8; Iout=3

Test points for power
